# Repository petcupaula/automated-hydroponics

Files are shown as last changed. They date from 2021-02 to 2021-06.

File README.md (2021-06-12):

# automated-hydroponics
Automated home garden using hydroponics concepts

## Components

* Net cup for hydroponics: buy or 3d print (https://www.thingiverse.com/make:893504)
* Plant grow lights (https://www.aliexpress.com/item/1005001599994011.html)
* DHT22 temperature and humidity sensor (https://learn.adafruit.com/dht)
* Light/color sensor AS7341 (https://www.adafruit.com/product/4698)
  * Instructions: https://learn.adafruit.com/adafruit-as7341-10-channel-light-color-sensor-breakout?view=all
  * Datasheet: https://ams.com/documents/20143/36005/AS7341_DS000504_3-00.pdf/
  * Connecting with Arduino Uno - Arduino library: Adafruit AS7341
  * Connecting with ESP32 - Arduino library: https://github.com/DFRobot/DFRobot_AS7341
* PH meter - DIYmore pH Sensor PH-4502C (https://www.aliexpress.com/item/32957428276.html)
  * Instructions: https://www.youtube.com/watch?v=zUEl3Y3yKL4&ab_channel=ElectronicClinic / https://www.electroniclinic.com/ph-meter-arduino-ph-meter-calibration-diymore-ph-sensor-arduino-code/ / https://cimpleo.com/blog/simple-arduino-ph-meter/ / https://scidle.com/how-to-use-a-ph-sensor-with-arduino/
  * Pins: V (Can be used with 5V and 3.3V compatible controller boards), GND, GND, Po (PH analog output), Do (3.3V pH limit trigger), To (analog temperature output)
* TDS sensor - (https://www.aliexpress.com/item/4001010691199.html)
  * Instructions: https://wiki.dfrobot.com/Gravity__Analog_TDS_Sensor___Meter_For_Arduino_SKU__SEN0244
  * Arduino library: https://github.com/DFRobot/GravityTDS
* Ultrasound mist - Water Atomization Grove actuator (https://www.seeedstudio.com/Grove-Water-Atomization-v1-0.html)
* Water level - HC-SR04 Ultrasonic Sensor
  * Instructions: https://howtomechatronics.com/tutorials/arduino/ultrasonic-sensor-hc-sr04/
* Fan 5V (https://www.adafruit.com/product/4468)
* Air pump 5V (https://www.adafruit.com/product/4700) 
* Air stone (https://www.aliexpress.com/item/32942776713.html)
* Submersible Water pump 5V (https://www.banggood.com/DIY-Automatic-Irrigation-Module-Kit-Soil-Moisture-Detection-Automatic-Watering-Pumping-p-1338728.html, https://arduinotech.dk/shop/automatic-watering-system-diy-set-b/)
* 4 x Relays
* Camera - 5MP RPi camera module (https://www.elextra.dk/p/GS/H37933), or even better, a wide-lense camera module (https://www.aliexpress.com/item/32714486681.html)
* Waterproof temperature sensor (https://wiki.dfrobot.com/Waterproof_DS18B20_Digital_Temperature_Sensor__SKU_DFR0198_)

## Schematics

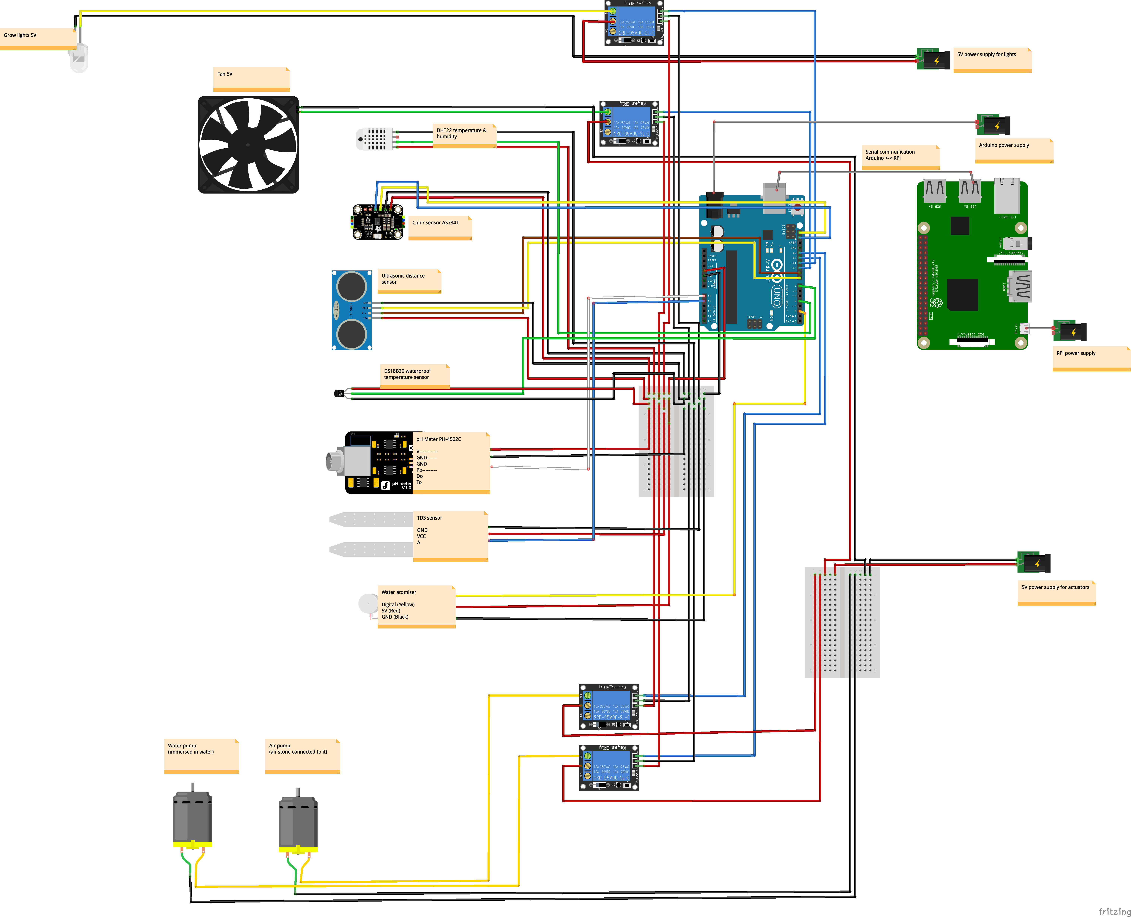
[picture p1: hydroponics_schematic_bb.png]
Schematics


## RPi setup

```
# Choose Menu > Preferences > Raspberry Pi Configuration
#>> Change pi password
#>> Change hostname to what you would like your RPi to be named.
#>> Enable SSH and VNC
# (A reboot will be needed after these changes)

# Camera setup
# RPi camera setup instructions: https://www.raspberrypi.org/documentation/configuration/camera.md

# Install a web interface for controlling the camera and doing timelapses
# Install instructions: https://elinux.org/RPi-Cam-Web-Interface

# Check to see if Arduino is seen
Should see /dev/ttyACM0
ls /dev/tty*

# Install Arduino IDE on RPi, though optional
sudo apt-get install arduino

# Install Arduino CLI
curl -fsSL https://raw.githubusercontent.com/arduino/arduino-cli/master/install.sh | BINDIR=/usr/local/bin sh
# Might need to fiddle a bit on where it is installed

arduino-cli core update-index
arduino-cli board list

# Install platform core for board Arduino Uno/Mega
arduino-cli core install arduino:avr

# Clone this project
cd ~
git clone https://github.com/petcupaula/automated-hydroponics.git

# Install Arduino libraries
# You can search for libraries using: arduino-cli lib search DHT
arduino-cli lib install "DHT sensor library"
arduino-cli lib install "Adafruit AS7341"
arduino-cli lib install "OneWire"
# Libraries to be installed from zip files - files will go into  /home/pi/Arduino/libraries/
cd /home/pi/Arduino/libraries/
git clone https://github.com/DFRobot/GravityTDS.git

# Test compile and upload from cmd line:
cd ~/automated_hydroponics
arduino-cli compile --fqbn arduino:avr:uno arduino_hydroponics/arduino_hydroponics.ino 
arduino-cli upload -p /dev/ttyACM0 --fqbn arduino:avr:uno arduino_hydroponics

# To communicate between Arduino and Raspberry Pi via serial, there are 
# three scripts that can be used

# The `arduino_com.py` sends a message via serial to the Arduino, which in turn returns sensor data
python3 arduino_com.py

# The `mqtt_client.py` is an enhanced version of that, but sends the data to an MQTT broker. 
# (Note: certificates will be required that are not included in this repo)
# Path to certificates can be added in config.py (see config_template.py for what is expected)
python3 mqtt_client.py

# Install Adafruit IO for sending and receiving data from Adafruit IO's MQTT broker
sudo pip3 install adafruit-io
# To communicate with Adafruit IO, and subscribe to the `hydroponics feed`
python3 aio_client.py

# To ensure the aio_client.py (or mqtt_client.py) are run at Raspberry Pi reboot:
sudo nano /etc/rc.local
# Add the following line before the exit:
sudo bash -c '/usr/bin/python3 /home/pi/automated-hydroponics/aio_client.py > /home/pi/Desktop/log.txt 2>&1' &
# Test it by restarting the Raspberry Pi:
sudo reboot
# And after reconnecting check that the python script is running:
ps aux | grep python

# That is it.
```

## Dashboard and command center

Example created in Adafruit IO:

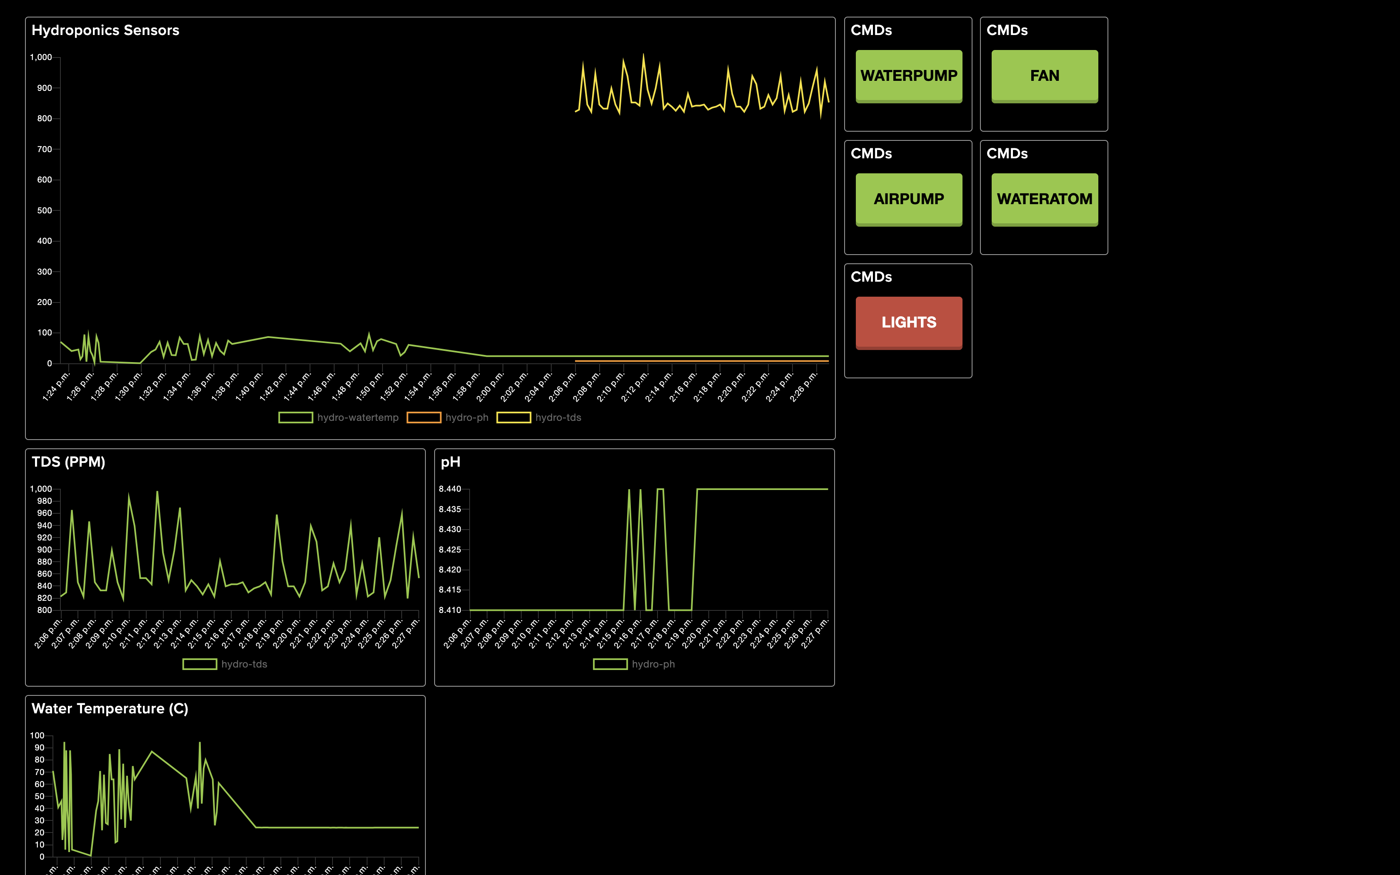
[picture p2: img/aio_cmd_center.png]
AIO_dash


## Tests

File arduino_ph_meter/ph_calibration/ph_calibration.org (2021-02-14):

# PH Calibration

pH were measured according to this schema.

#+NAME: ph
| Substance       |   pH | Voltage |
|-----------------+------+---------|
| Vinegar         |  2.5 |    3.39 |
| Caustic Soda    | 12.5 |    1.51 |
| Distilled Water |  7.0 |    2.71 |

A linear regression was performed to calculate offset and
coefficient.

#+begin_src R :exports all :var ph=ph :results output :session *R*
  regr <- lm(pH ~ Voltage, ph)
  summary(regr)
#+end_src

#+RESULTS:
#+begin_example

Call:
lm(formula = pH ~ Voltage, data = ph)

Residuals:
      1       2       3 
-0.3664 -0.2076  0.5740 

Coefficients:
            Estimate Std. Error t value Pr(>|t|)  
(Intercept)  20.6120     1.4031  14.691   0.0433 *
Voltage      -5.2347     0.5288  -9.898   0.0641 .
---
Signif. codes:  0 ‘***’ 0.001 ‘**’ 0.01 ‘*’ 0.05 ‘.’ 0.1 ‘ ’ 1

Residual standard error: 0.7119 on 1 degrees of freedom
Multiple R-squared:  0.9899,	Adjusted R-squared:  0.9798 
F-statistic: 97.98 on 1 and 1 DF,  p-value: 0.0641
#+end_example

And finally the regression is compared to the measured values.

#+begin_src R :exports all :results output graphics :session *R*  :file ph.png
  plot(ph$Voltage, ph$pH, xlab="Voltage", ylab="pH")
  abline(regr)
#+end_src

#+RESULTS:

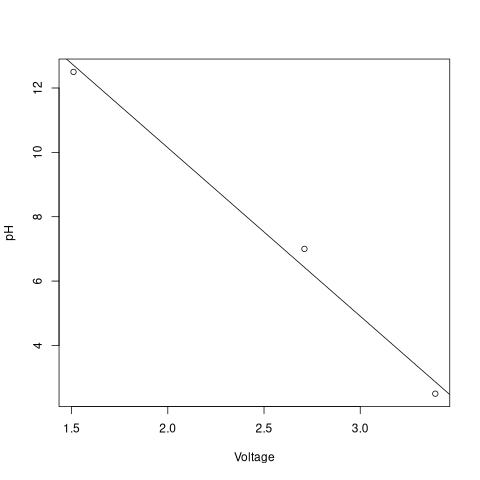
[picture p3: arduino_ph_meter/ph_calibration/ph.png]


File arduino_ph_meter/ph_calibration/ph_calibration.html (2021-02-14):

pH were measured according to this schema.

Substance | pH | Voltage
Vinegar | 2.5 | 3.39
Caustic Soda | 12.5 | 1.51
Distilled Water | 7.0 | 2.71

A linear regression was performed to calculate offset and coefficient.

regr <- lm(pH ~ Voltage, ph)
summary(regr)

Call:
lm(formula = pH ~ Voltage, data = ph)

Residuals:
      1       2       3 
-0.3664 -0.2076  0.5740 

Coefficients:
            Estimate Std. Error t value Pr(>|t|)  
(Intercept)  20.6120     1.4031  14.691   0.0433 *
Voltage      -5.2347     0.5288  -9.898   0.0641 .
---
Signif. codes:  0 ‘***’ 0.001 ‘**’ 0.01 ‘*’ 0.05 ‘.’ 0.1 ‘ ’ 1

Residual standard error: 0.7119 on 1 degrees of freedom
Multiple R-squared:  0.9899,	Adjusted R-squared:  0.9798 
F-statistic: 97.98 on 1 and 1 DF,  p-value: 0.0641

And finally the regression is compared to the measured values.

plot(ph$Voltage, ph$pH, xlab="Voltage", ylab="pH")
abline(regr)



Created: 2021-02-14 Sun 14:26

Validate (https://validator.w3.org/check?uri=referer)

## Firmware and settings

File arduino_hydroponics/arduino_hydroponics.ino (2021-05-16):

#include "DHT.h"
#include <Adafruit_AS7341.h>
#include <EEPROM.h>
#include "GravityTDS.h"
#include <OneWire.h>

// DHT - temp & humidity
#define DHTPIN 4
#define DHTTYPE DHT22
DHT dht(DHTPIN, DHTTYPE);

// Ultrasonic sensor - distance
#define TRIGPIN 9
#define ECHOPIN 8
long duration;
int distance;

// Color sensor AS7341
Adafruit_AS7341 as7341;

// TDS sensor
#define TDSPIN A1
GravityTDS gravityTds;
float temperature = 25.0;
float tdsValue = 0;
float vplusTDS = 5; // connected to 3.3 or 5V

// pH sensor
#define PHPIN A0
int phpin_value; 
int vplusPH = 5; // connected to 3.3 or 5V
float ph_offset = 21.34;//20.61;
float ph_coefficient = -5.72;//-5.23;

float adcRef = 1024.0;

// Water temperature using DS18S20
#define TEMPPIN 7
OneWire ds(TEMPPIN);

// Fan
#define FANPIN 12
bool fanOn = false;

// Grow lights
#define LIGHTPIN 13
bool lightsOn = true;

// Water atomizer
#define ATOMPIN 2
bool waterAtomOn = false;

// Air pump
#define AIRPIN 11
bool airPumpOn = false;

// Water pump
#define WATERPIN 10
bool waterPumpOn = false;

void setup()
{
  Serial.begin(9600);
  
  dht.begin();

  pinMode(TRIGPIN, OUTPUT);
  pinMode(ECHOPIN, INPUT);

  as7341.begin();
  as7341.setATIME(100);
  as7341.setASTEP(999);
  as7341.setGain(AS7341_GAIN_256X);

  gravityTds.setPin(TDSPIN);
  gravityTds.setAref(vplusTDS);
  gravityTds.setAdcRange(adcRef);
  gravityTds.begin();

  pinMode(FANPIN, OUTPUT);
  turnFanOff();
  
  pinMode(LIGHTPIN, OUTPUT);
  turnLightsOn();

  pinMode(ATOMPIN, OUTPUT);

  pinMode(AIRPIN, OUTPUT);
  turnAirPumpOff();
  
  pinMode(WATERPIN, OUTPUT);
  turnWaterPumpOff();

  //Serial.println("Starting...");
  
}

void loop()
{

  // Wait a few seconds between measurements.
  // delay(5000);
  
  if (Serial.available() > 0) {
      String data = Serial.readStringUntil('\n');
      //Serial.print("You sent me (string): ");
      //Serial.println(data);

    if (data == "READ") {
      Serial.print("{");
      getUltrasonic();
      getDHT();
      getColors();
      getTDS();
      getPH();
      getWaterTemp();
      Serial.print(", 'airPumpOn': ");
      Serial.print(airPumpOn);
      Serial.print(", 'waterPumpOn': ");
      Serial.print(waterPumpOn);
      Serial.print(", 'waterAtomOn': ");
      Serial.print(waterAtomOn);
      Serial.print(", 'lightsOn': ");
      Serial.print(lightsOn);
      Serial.print(", 'fanOn': ");
      Serial.print(fanOn);
      Serial.println("}");
    }

    if (data == "AIRPUMP") {
      if (airPumpOn == false) {
        turnAirPumpOn();
      }
      else {
        turnAirPumpOff();
      }
    }

    if (data == "WATERPUMP") {
      if (waterPumpOn == false) {
        turnWaterPumpOn();
      }
      else {
        turnWaterPumpOff();
      }
    }

    if (data == "WATERATOM") {
      if (waterAtomOn == false) {
        turnWaterAtomOn();
      }
      else {
        turnWaterAtomOff();
      }
    }

    if (data == "LIGHTS") {
      if (lightsOn == false) {
        turnLightsOn();
      }
      else {
        turnLightsOff();
      }
    }

    if (data == "FAN") {
      if (fanOn == false) {
        turnFanOn();
      }
      else {
        turnFanOff();
      }
    }
  }

}


void getUltrasonic() {
  // Clear the trigPin
  digitalWrite(TRIGPIN, LOW);
  delayMicroseconds(2);
  
  // Set the trigPin on HIGH state for 10 micro seconds
  digitalWrite(TRIGPIN, HIGH);
  delayMicroseconds(10);
  digitalWrite(TRIGPIN, LOW);
  
  // Read the echoPin, return the sound wave travel time in microseconds
  duration = pulseIn(ECHOPIN, HIGH);
  
  // Calculate the distance
  // The speed of sound is 0.034 cm/ns
  // time = distance / speed => distance = time * speed
  // but /2 because sound has at this point traveled towards and back from the object
  distance = duration * 0.034 / 2;
  
  Serial.print("'Distance (cm)': ");
  Serial.print(distance);
}

void getDHT() {
  // Reading temperature or humidity takes about 250 milliseconds!
  // Sensor readings may also be up to 2 seconds 'old' (its a very slow sensor)
  float h = dht.readHumidity();
  // Read temperature as Celsius (the default)
  float t = dht.readTemperature();

  // Check if any reads failed and exit early (to try again).
  if (isnan(h) || isnan(t)) {
    //Serial.println(F("Failed to read from DHT sensor!"));
    return;
  }

  temperature = t;

  Serial.print(F(", 'Humidity (%)': "));
  Serial.print(h);
  Serial.print(F(", 'Temperature (C)': "));
  Serial.print(t);  
}

void getColors() {
  // Read all channels at the same time and store in as7341 object
  if (!as7341.readAllChannels()){
    //Serial.println("Error reading all channels!");
    return;
  }

  // Print out the stored values for each channel
  Serial.print(", 'F1 415nm (Violet)': ");
  Serial.print(as7341.getChannel(AS7341_CHANNEL_415nm_F1));
  Serial.print(", 'F2 445nm (Indigo)': ");
  Serial.print(as7341.getChannel(AS7341_CHANNEL_445nm_F2));
  Serial.print(", 'F3 480nm (Blue)': ");
  Serial.print(as7341.getChannel(AS7341_CHANNEL_480nm_F3));
  Serial.print(", 'F4 515nm (Cyan)': ");
  Serial.print(as7341.getChannel(AS7341_CHANNEL_515nm_F4));
  Serial.print(", 'F5 555nm (Green)': ");
  Serial.print(as7341.getChannel(AS7341_CHANNEL_555nm_F5));
  Serial.print(", 'F6 590nm (Yellow)': ");
  Serial.print(as7341.getChannel(AS7341_CHANNEL_590nm_F6));
  Serial.print(", 'F7 630nm (Orange)': ");
  Serial.print(as7341.getChannel(AS7341_CHANNEL_630nm_F7));
  Serial.print(", 'F8 680nm (Red)': ");
  Serial.print(as7341.getChannel(AS7341_CHANNEL_680nm_F8));
  Serial.print(", 'Clear': ");
  Serial.print(as7341.getChannel(AS7341_CHANNEL_CLEAR));
  Serial.print(", 'Near IR': ");
  Serial.print(as7341.getChannel(AS7341_CHANNEL_NIR));
}

void getTDS() {
  gravityTds.setTemperature(temperature);  // set the temperature and execute temperature compensation
  gravityTds.update();  //sample and calculate 
  tdsValue = gravityTds.getTdsValue();  // then get the value
  Serial.print(", 'TDS_V': ");
  Serial.print(voltage(analogRead(TDSPIN),vplusTDS));
  Serial.print(", 'TDS_Vref': ");
  Serial.print(vplusTDS);
  Serial.print(", 'TDS_aSteps': ");
  Serial.print(adcRef,0);
  Serial.print(", 'PPM': ");
  Serial.print(tdsValue);
}


float ph(int val) {
  return  ph_coefficient* voltage(val, vplusPH) + ph_offset;
}

float voltage(int val, int vRef) {
  return val * vRef / adcRef; 
}

void getPH() {
  phpin_value = analogRead(PHPIN); 
  Serial.print(", 'pH_V': ");
  Serial.print(voltage(phpin_value, vplusPH));
  Serial.print(", 'pH_Vref': ");
  Serial.print(vplusPH);
  Serial.print(", 'ph_aSteps': ");
  Serial.print(adcRef,0);
  Serial.print(", 'pH': ");
  Serial.print(ph(phpin_value));
}

void getWaterTemp(){
  //returns the temperature from one DS18S20 in DEG Celsius

  byte data[12];
  byte addr[8];

  if ( !ds.search(addr)) {
      //no more sensors on chain, reset search
      ds.reset_search();
      return -1000;
  }

  if ( OneWire::crc8( addr, 7) != addr[7]) {
      //Serial.println("CRC is not valid!");
      return -1000;
  }

  if ( addr[0] != 0x10 && addr[0] != 0x28) {
      //Serial.print("Device is not recognized");
      return -1000;
  }

  ds.reset();
  ds.select(addr);
  ds.write(0x44,1); // start conversion, with parasite power on at the end

  byte present = ds.reset();
  ds.select(addr);
  ds.write(0xBE); // Read Scratchpad


  for (int i = 0; i < 9; i++) { // we need 9 bytes
    data[i] = ds.read();
  }

  ds.reset_search();

  byte MSB = data[1];
  byte LSB = data[0];

  float tempRead = ((MSB << 8) | LSB); //using two's compliment
  float TemperatureSum = tempRead / 16;

  Serial.print(F(", 'Water Temperature (C)': "));
  Serial.print(TemperatureSum);
}

void turnFanOn() {
  digitalWrite(FANPIN, LOW);
  fanOn = true;
}

void turnFanOff() {
  digitalWrite(FANPIN, HIGH);
  fanOn = false;
}

void turnLightsOn() {
  digitalWrite(LIGHTPIN, HIGH);
  lightsOn = true;
}

void turnLightsOff() {
  digitalWrite(LIGHTPIN, LOW);
  lightsOn = false;
}

void turnWaterAtomOn() {
  digitalWrite(ATOMPIN, HIGH);
  waterAtomOn = true;
}

void turnWaterAtomOff() {
  digitalWrite(ATOMPIN, LOW);
  waterAtomOn = false;
}

void turnAirPumpOn() {
  digitalWrite(AIRPIN, LOW);
  airPumpOn = true;
}

void turnAirPumpOff() {
  digitalWrite(AIRPIN, HIGH);
  airPumpOn = false;
}

void turnWaterPumpOn() {
  digitalWrite(WATERPIN, LOW);
  waterPumpOn = true;
}

void turnWaterPumpOff() {
  digitalWrite(WATERPIN, HIGH);
  waterPumpOn = false;
}

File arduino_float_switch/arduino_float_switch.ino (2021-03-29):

int floatSwitch = 3;

void setup() {
  Serial.begin(9600);
  pinMode(floatSwitch, INPUT_PULLUP);
}

void loop() {
  
  int floatState = digitalRead(floatSwitch);

  if (floatState == LOW) 
  { 
    Serial.println( "WATER LEVEL - HIGH"); 
  } 
  else 
  { 
    Serial.println( "WATER LEVEL - LOW" ); 
  } 
  delay(1000);
}

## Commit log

2021-02-14 Add ph meter arduino code
2021-02-14 Add pH calibration data
2021-02-14 Use the new calibrated ph offset and coefficient
2021-02-14 Average over several ph meter value samples
2021-02-14 Add arduino code for reading from color sensor
2021-02-14 Add code for reading color sensor values with esp32
2021-02-14 Add schematics
    [hydroponics_schematic.fzz]
2021-03-29 Add code for working with various sensors and actuators
2021-03-29 Add combined arduino sketch
    [hydroponics_schematic.fzz]
2021-03-29 Add code for handling actuators
2021-03-29 Add arduino raspberry pi communication
2021-04-01 Update pin numbers on arduino after soldering operation
2021-04-22 Add code for serial communication of actuators toggling
2021-04-22 Read water temperature
2021-04-22 Update client to start an actuator once in a while
2021-04-25 Update schematic based on latest adjustments
    [hydroponics_schematic.fzz]
2021-05-16 Handle case when arduino is reconnected and port changes
2021-05-16 Send sensor data to Adafruit IO
2021-05-16 Change the order sensor data is sent by arduino
